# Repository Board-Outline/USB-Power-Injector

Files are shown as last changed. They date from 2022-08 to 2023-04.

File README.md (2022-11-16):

# USB Power Injector

The USB Power Injector allows a convenient way to power up USB 2.0 devices from a lab power supply, while still allowing data transfer from the device to the host. 

## The problem

When powering devices from a standard USB 2.0 port, either from a PC or from a standard USB hub, you never have the niceties that an adjustable lab style power supply has. 
During development that means you can’t set precise voltage and current limits. In the best case scenario, that means you can’t test under/over voltage protections. 
In the worst case, you run excessive current trough your device and you don’t even know that’s happened.
USB hubs tend to have overcurrent protection, but most don’t send the overcurrent event to the operating system. 
That can cause confusion and loss of time for a hardware engineer during development or to testing personnel during production.  

# Open Source Certified

The USB Power Injector is officially certified by the Open Source Hardware Association, with certificate number BG000082.

<p align="center">
  
</p>

The project was made using KiCad.

# License

<p align="center">
  
</p>

The project is released under the [Creative Commons Attribution-ShareAlike 4.0 International (CC BY-SA 4.0)](https://creativecommons.org/licenses/by-sa/4.0/).

Note: This is a human-readable summary of (and not a substitute for) the [license](https://creativecommons.org/licenses/by-sa/4.0/legalcode).

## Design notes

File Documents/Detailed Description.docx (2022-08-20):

Nikola Manolov

Board Outline

USB Power Injector

DETAILED DESCRIPTION


# Document Changes

Document Version | Date | Author | Changes
V1.0 | 2022.07.30 | Nikola Manolov | Document Creation

# Purpose and main design requirements

The USB Power Injector is an open source PCB designed by Board Outline.

Its intent is simple – Allow a convenient way to power up USB 2.0 devices from a lab power supply. When powering devices from a standard USB 2.0 port, either from a PC or from a standard USB hub, you never have the niceties that an adjustable lab style power supply has. During development that means you can’t set precise voltage and you can’t set current limits. In the best case scenario, that means you can’t test under/over voltage protections. In the worst case, you run excessive current trough your device and you don’t even know that’s happened. USB hubs tend to have overcurrent protection, but most don’t send the overcurrent event to the operating system. That can cause confusion and loss of time for a hardware engineer during development or to testing personnel during production.

When you get to that point its common to sacrifice a standard USB cable so you can connect an amp meter or to modify your board in a way that allows a bodged external supply to be used. Neither is pretty, quick or convenient.

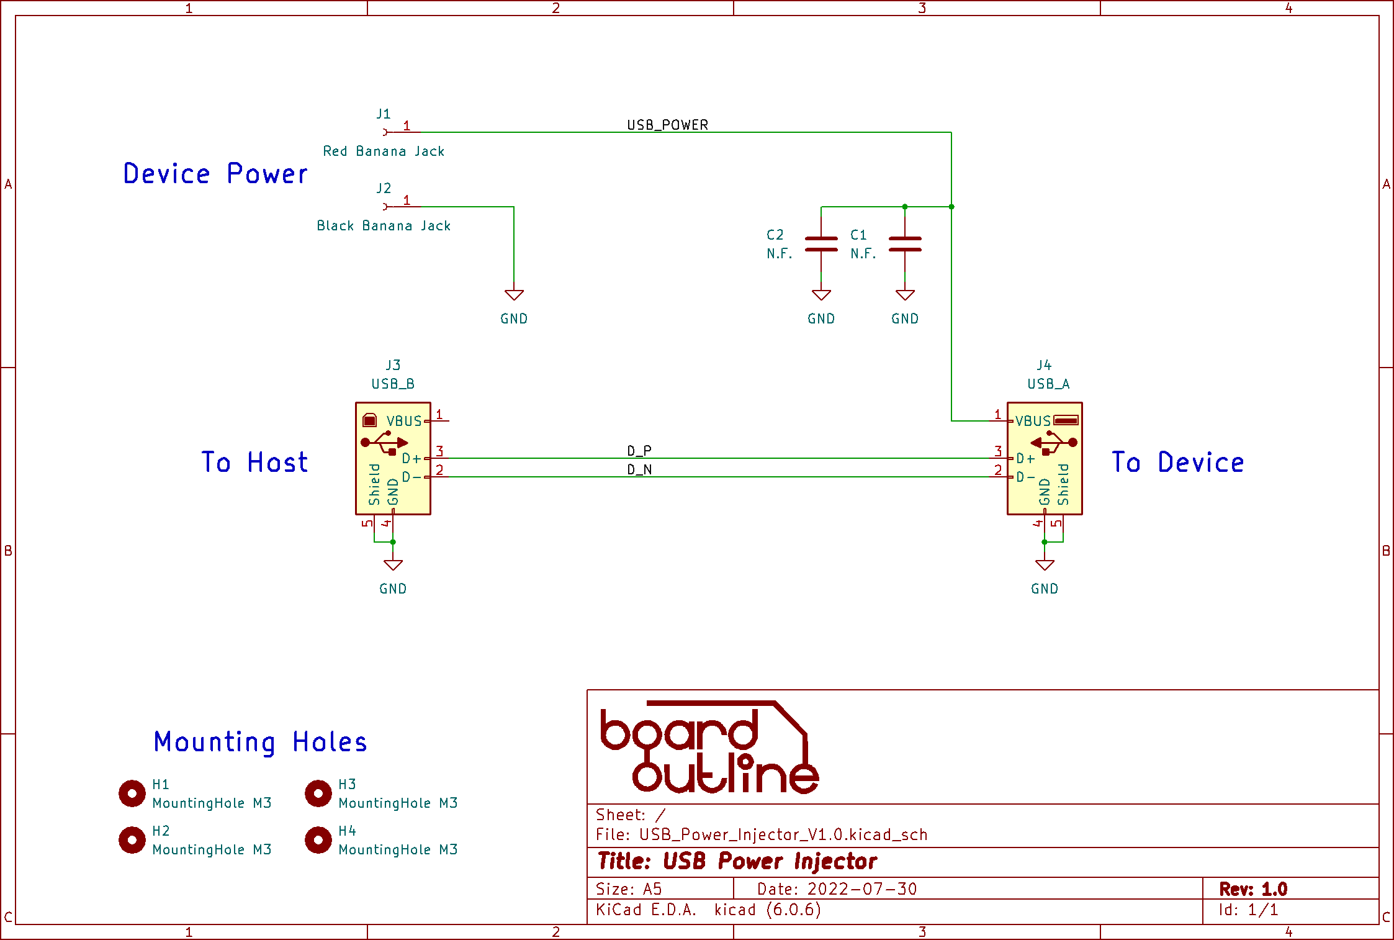
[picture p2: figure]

The USB Power Injector aims to remedy that by powering your device from two standard 4mm banana plugs, while still passing data between the host and device USB ports.
The device needs to be as transparent as possible for both the USB Data signals and for the power signals.

Figure 1. Schematic

# Detailed design explanation

The schematic is shown on Figure 1. The board was designed using KiCad 6. It’s a free and open source software, so anyone can read or edit the original design files.

## Design overview of the data path.

Connectors used for the data part are a horizontal USB B for the connection to the host and a horizontal USB A connector for the connection to the device under test. In order to get the required 90Ω impedance for USB lines, a 4 layer board was used. Stack used was JLC’s JLC7628. A conservative Space/Width of 5/8.1mils (0.127mm/0.2mm) was used, in order to get higher yield during manufacturing. As per the transparency requirement, no series or parallel components were used.

USB A and B connectors were used instead of two USB C connectors for the following reasons:

1. USB A and B connectors are physically stronger than USB C.
2. If two USB C connectors were used, the user could accidently connect his lab power supply to the power pins of the host USB port. That is potentially dangerous.

## Design overview of the power path.

Horizontal 4mm banana plugs were used in order to match the cable orientation of the USB ports/cables. Thus making the board less lightly to be moved by the cables by accident. The plugs are color coded – red for positive and black for negative. On the PCB they are positioned in the standard ¾ of an inch (19.04mm), so the user can use any standard banana plug accessories he may require.

As per the transparency requirement, no series elements, like diodes, were added. This allows the user to test any reverse polarity protection that may be present on the device under test. Parallel to the power line, unpopulated footprints for two 1210 capacitors were added close to the USB A connector. Their intent is to give the used the opportunity to add capacitors that would compensate the inductance of the power cables to the power supply. They are not populated in order to make sure the power injector does not improve the power delivery system of the device under test and making it seem like its working as intended, when in fact it is not.

Board OutlineUSB Power Injector[Publish Date]

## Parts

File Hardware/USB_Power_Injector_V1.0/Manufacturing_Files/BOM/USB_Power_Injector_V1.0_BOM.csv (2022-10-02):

Source: | D:\Board Outline\Repos\USB-Power-Injector\Hardware\USB_Power_Injector_V1.0\USB_Power_Injector_V1.0.kicad_sch
Date: | 02-Oct-22 17:32:15
Tool: | Eeschema (6.0.6)
Generator: | C:\Program Files\KiCad\6.0\bin\scripting\plugins/bom_csv_grouped_by_value.py
Component Count: | 4
Individual Components:
Item | Qty | Reference(s) | Value | LibPart | Footprint | Datasheet | Manufacturer | Manufacturer Part Number
 |  | J1 | Red Banana Jack | Connector:Conn_01x01_Female | USB_Power_Injector:4mm_Banana_Jack_Red_Deltron_571-0500 | ~ | Deltron | 571-0500
 |  | J2 | Black Banana Jack | Connector:Conn_01x01_Female | USB_Power_Injector:4mm_Banana_Jack_Black_Deltron_571-0100 | ~ | Deltron | 571-0100
 |  | J3 | USB_B | Connector:USB_B | USB_Power_Injector:USB_B_OST_USB-B1HSxx_Horizontal | ~ | CUI Devices | UJ2-BH-1-TH
 |  | J4 | USB_A | Connector:USB_A | USB_Power_Injector:USB_A_CONNFLY_DS1095-WNR0 | ~ | Stewart Connector / Bel | SS-52100-001
Collated Components:
Item | Qty | Reference(s) | Value | LibPart | Footprint | Datasheet | Manufacturer | Manufacturer Part Number
1 | 1 | J1 | Red Banana Jack | Connector:Conn_01x01_Female | USB_Power_Injector:4mm_Banana_Jack_Red_Deltron_571-0500 | ~ | Deltron | 571-0500
2 | 1 | J2 | Black Banana Jack | Connector:Conn_01x01_Female | USB_Power_Injector:4mm_Banana_Jack_Black_Deltron_571-0100 | ~ | Deltron | 571-0100
3 | 1 | J3 | USB_B | Connector:USB_B | USB_Power_Injector:USB_B_OST_USB-B1HSxx_Horizontal | ~ | CUI Devices | UJ2-BH-1-TH
4 | 1 | J4 | USB_A | Connector:USB_A | USB_Power_Injector:USB_A_CONNFLY_DS1095-WNR0 | ~ | Stewart Connector / Bel | SS-52100-001

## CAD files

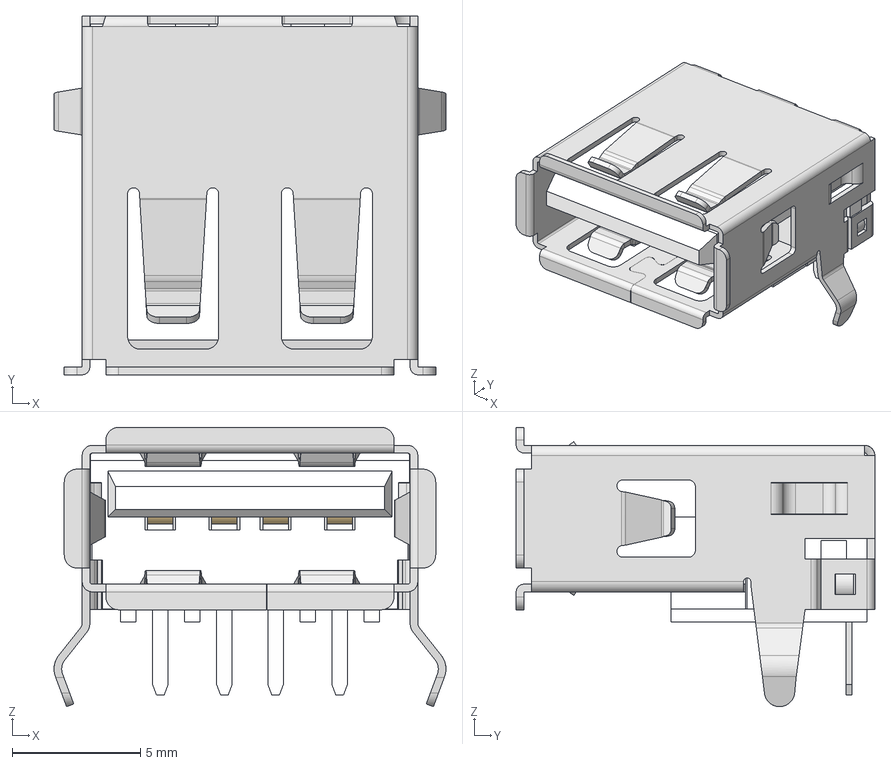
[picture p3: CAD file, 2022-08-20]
Hardware/USB_Power_Injector_V1.0/3D Models/Download_STP_61400416021 (rev1).stp
15.3 x 14.0 x 10.9 mm
61400416021_Insulator
61400416021_Contact Plating x 4
61400416021_Shielding

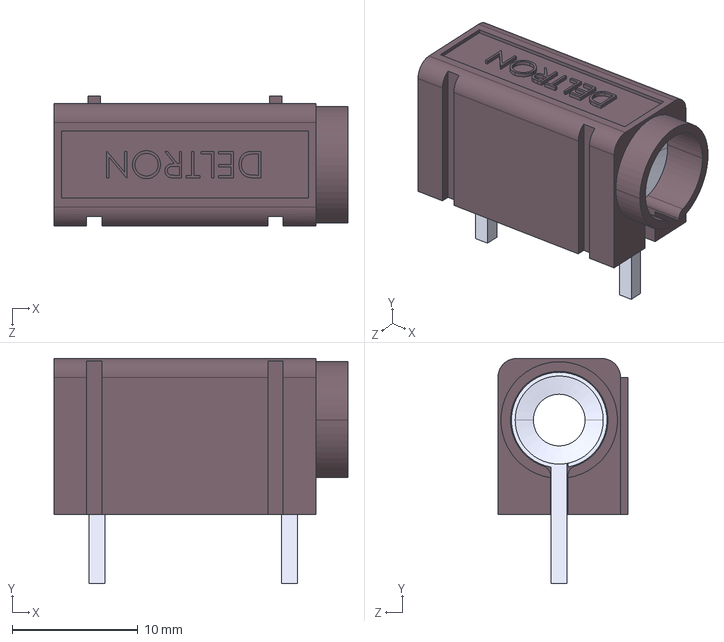
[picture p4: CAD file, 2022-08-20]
Hardware/USB_Power_Injector_V1.0/3D Models/deltron-571-0100-4mm-90deg-single-socket-data.step
23.4 x 17.9 x 10.3 mm

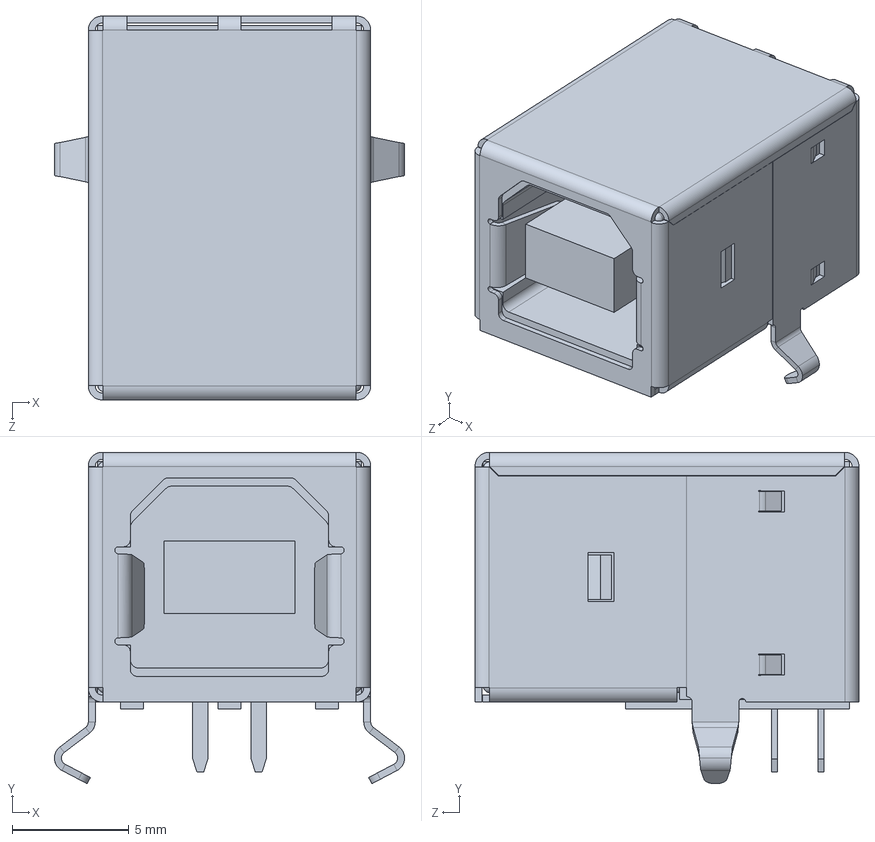
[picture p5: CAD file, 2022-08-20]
Hardware/USB_Power_Injector_V1.0/3D Models/CUI_DEVICES_UJ2-BH-1-TH.step
15.0 x 14.2 x 16.5 mm

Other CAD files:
Hardware/USB_Power_Injector_V1.0/3D Models/deltron-571-0500-4mm-90deg-single-socket-data.STEP

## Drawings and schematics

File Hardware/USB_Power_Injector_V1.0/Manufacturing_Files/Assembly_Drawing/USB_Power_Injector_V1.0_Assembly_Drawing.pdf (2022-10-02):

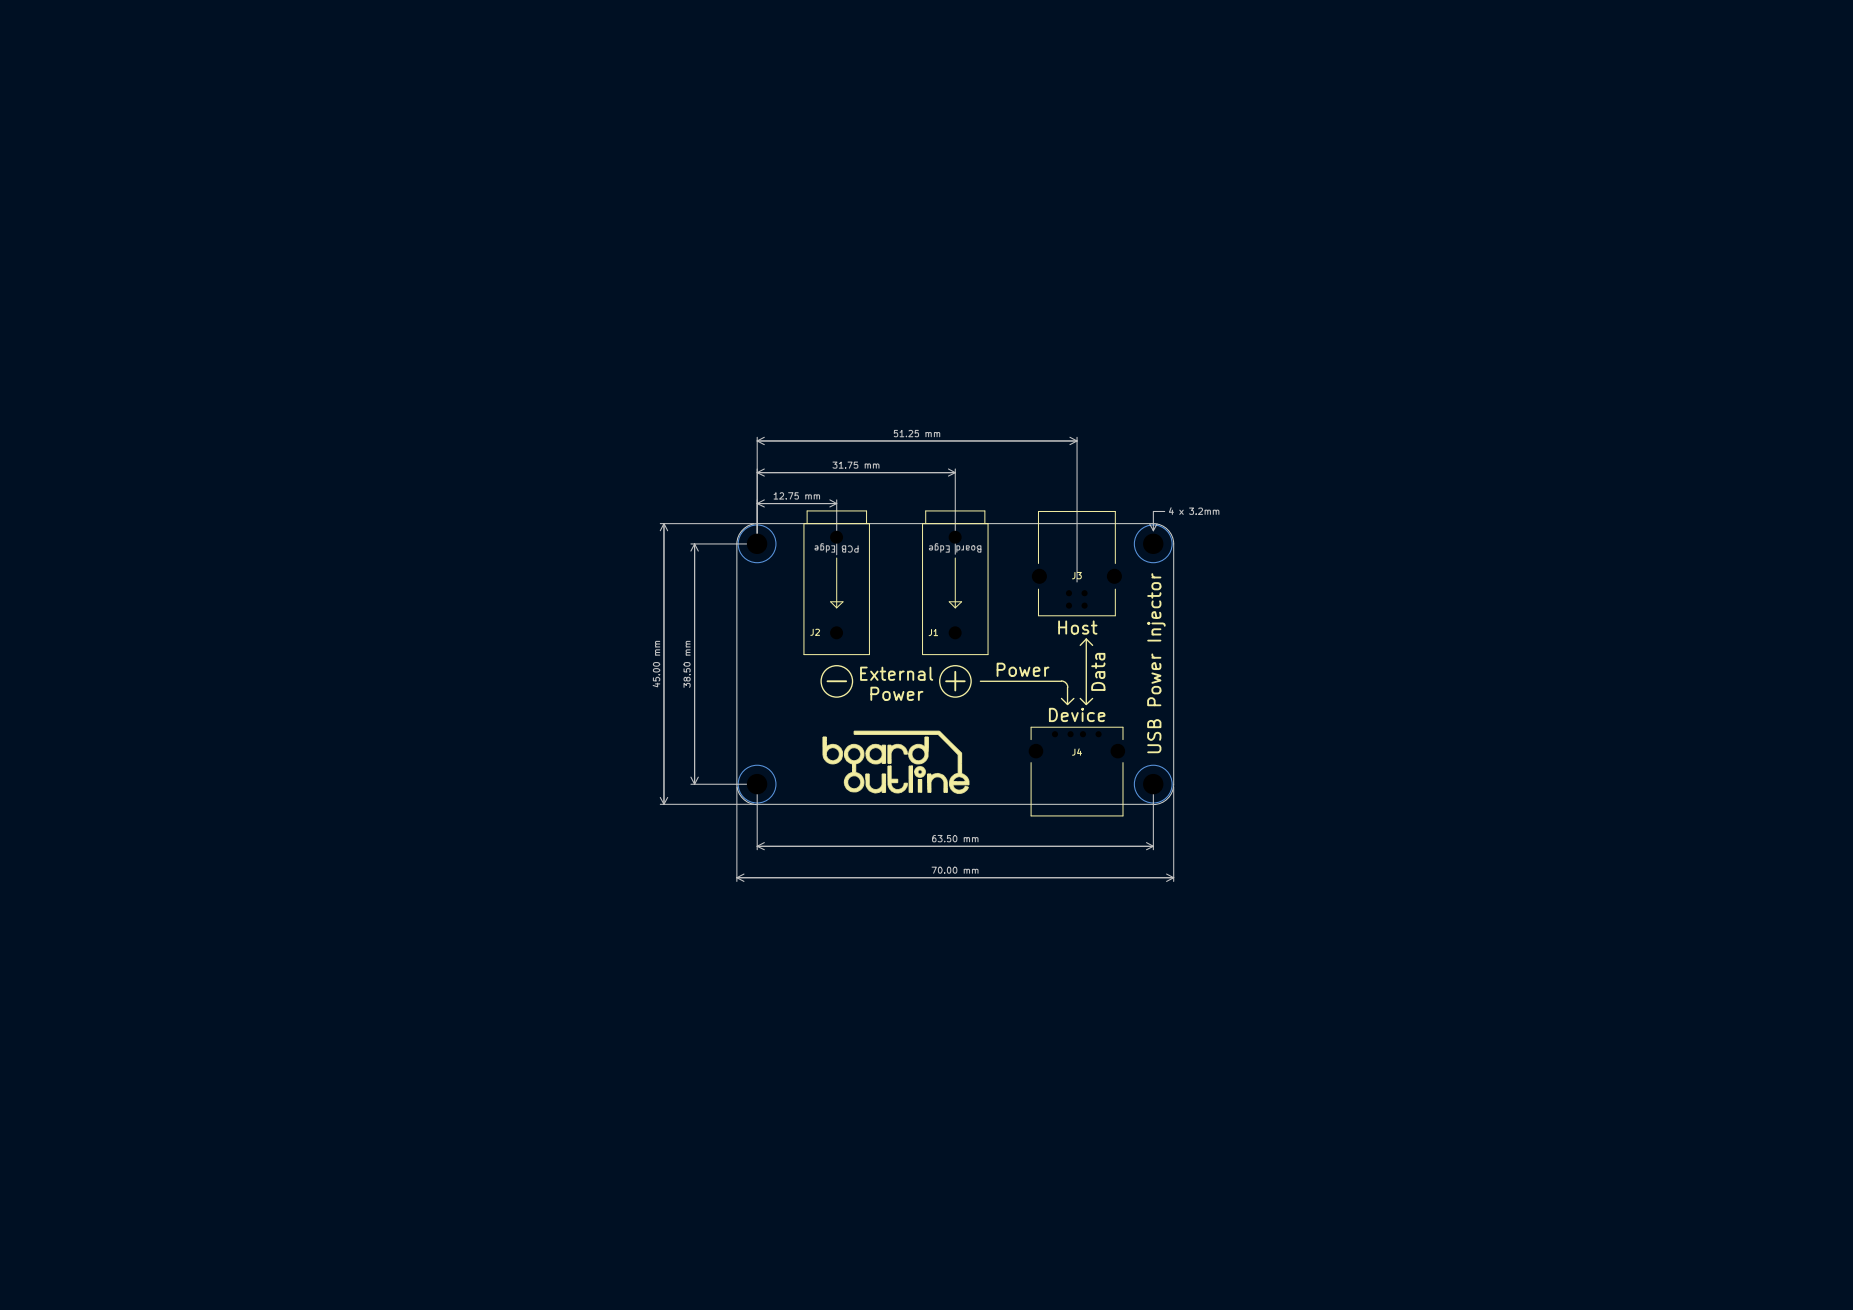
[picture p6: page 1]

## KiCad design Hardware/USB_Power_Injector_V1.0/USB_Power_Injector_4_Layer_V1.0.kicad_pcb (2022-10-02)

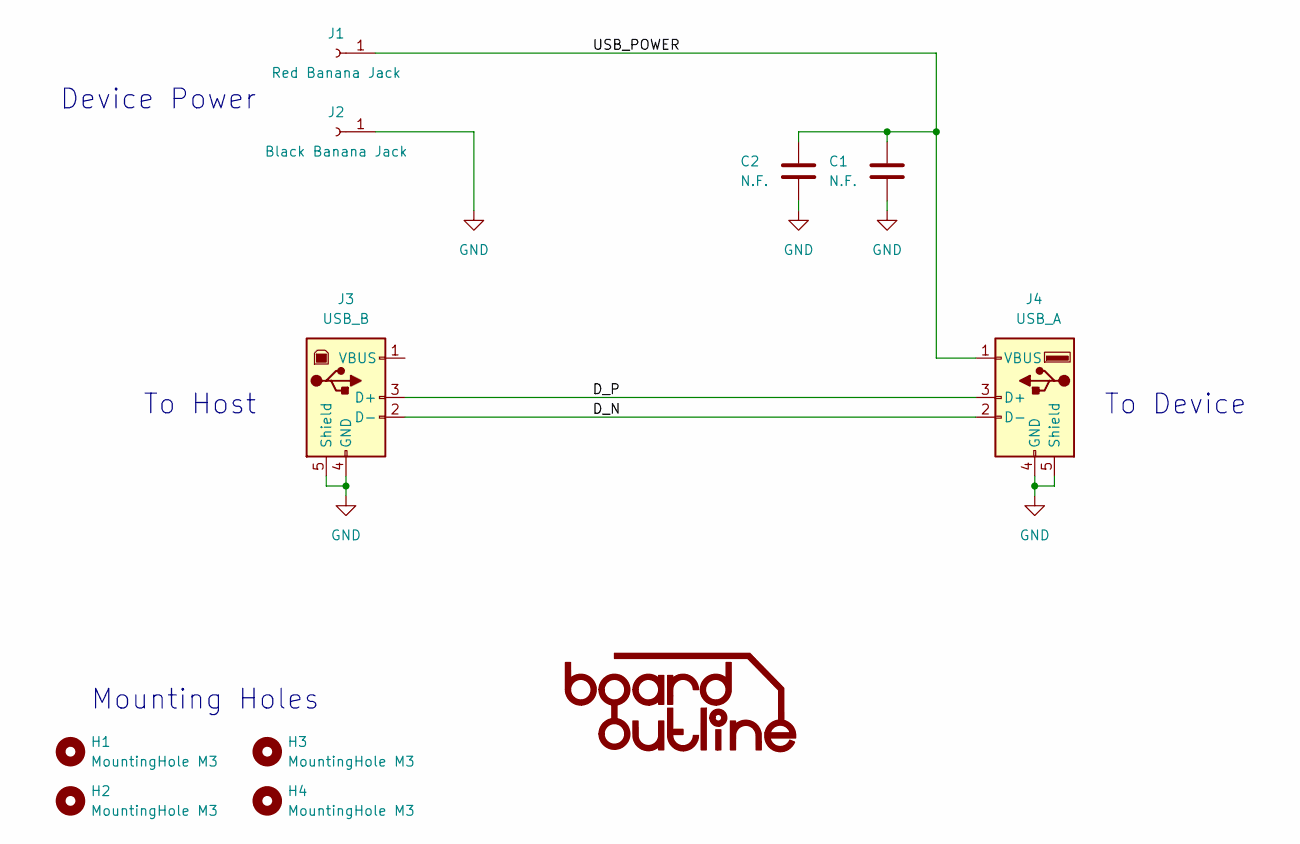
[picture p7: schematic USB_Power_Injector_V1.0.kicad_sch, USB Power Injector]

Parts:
C1, C2: N.F.; C_1210_3225Metric_Pad1.33x2.70mm_HandSolder
H1, H2, H3, H4: MountingHole M3; MountingHole_3.2mm_M3_ISO7380
J1: Red Banana Jack; 4mm_Banana_Jack_Red_Deltron_571-0500; Manufacturer Part Number 571-0500
J2: Black Banana Jack; 4mm_Banana_Jack_Black_Deltron_571-0100; Manufacturer Part Number 571-0100
J3: USB_B; USB_B_OST_USB-B1HSxx_Horizontal; Manufacturer Part Number UJ2-BH-1-TH
J4: USB_A; USB_A_CONNFLY_DS1095-WNR0; Manufacturer Part Number SS-52100-001

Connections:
/D_N: J3.2 (D-), J4.2 (D-)
/D_P: J3.3 (D+), J4.3 (D+)
/USB_POWER: C1.1, C2.1, J1.1, J4.1 (VBUS)
GND: C1.2, C2.2, J2.1, J3.4 (GND), J3.5 (Shield), J4.4 (GND), J4.5 (Shield)

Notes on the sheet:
Mounting Holes
To Device
Device Power
To Host

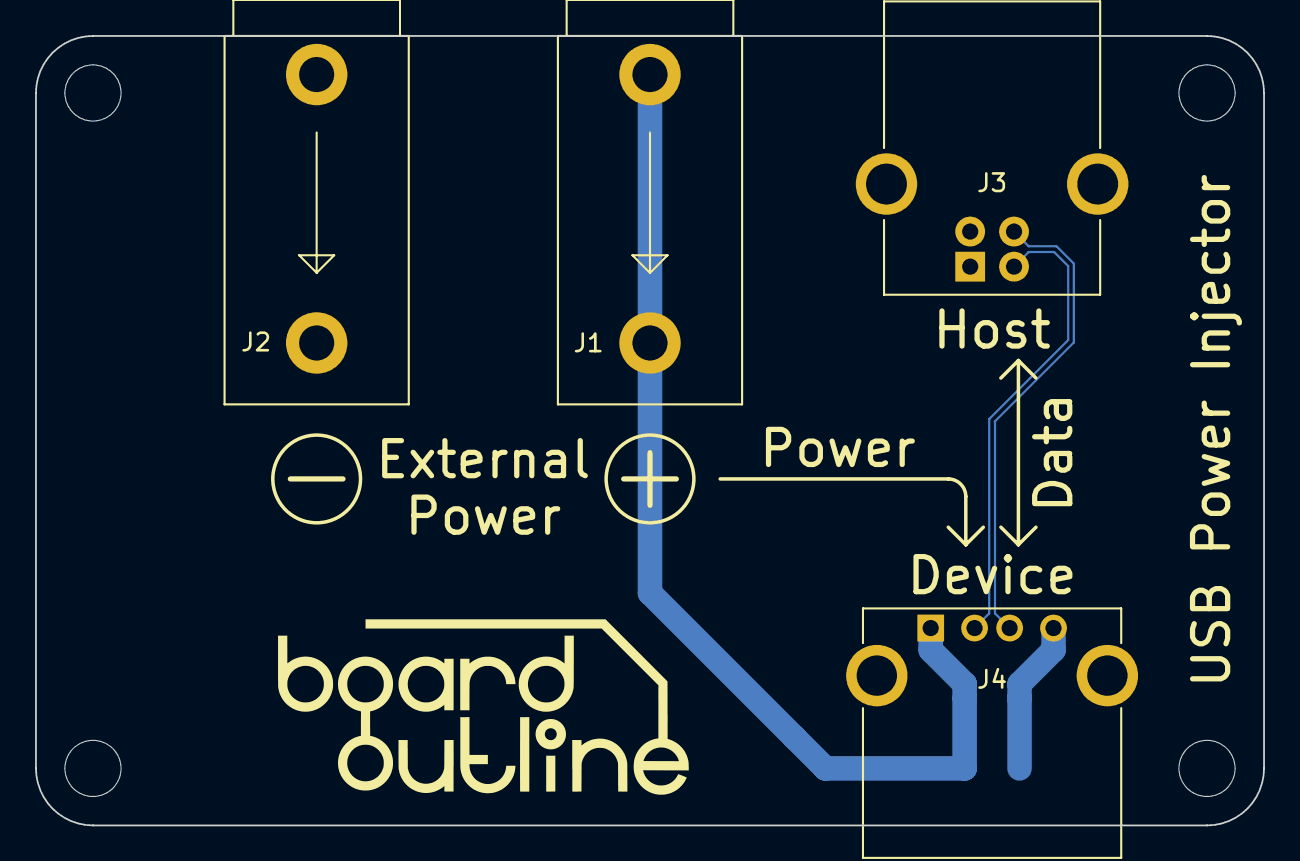
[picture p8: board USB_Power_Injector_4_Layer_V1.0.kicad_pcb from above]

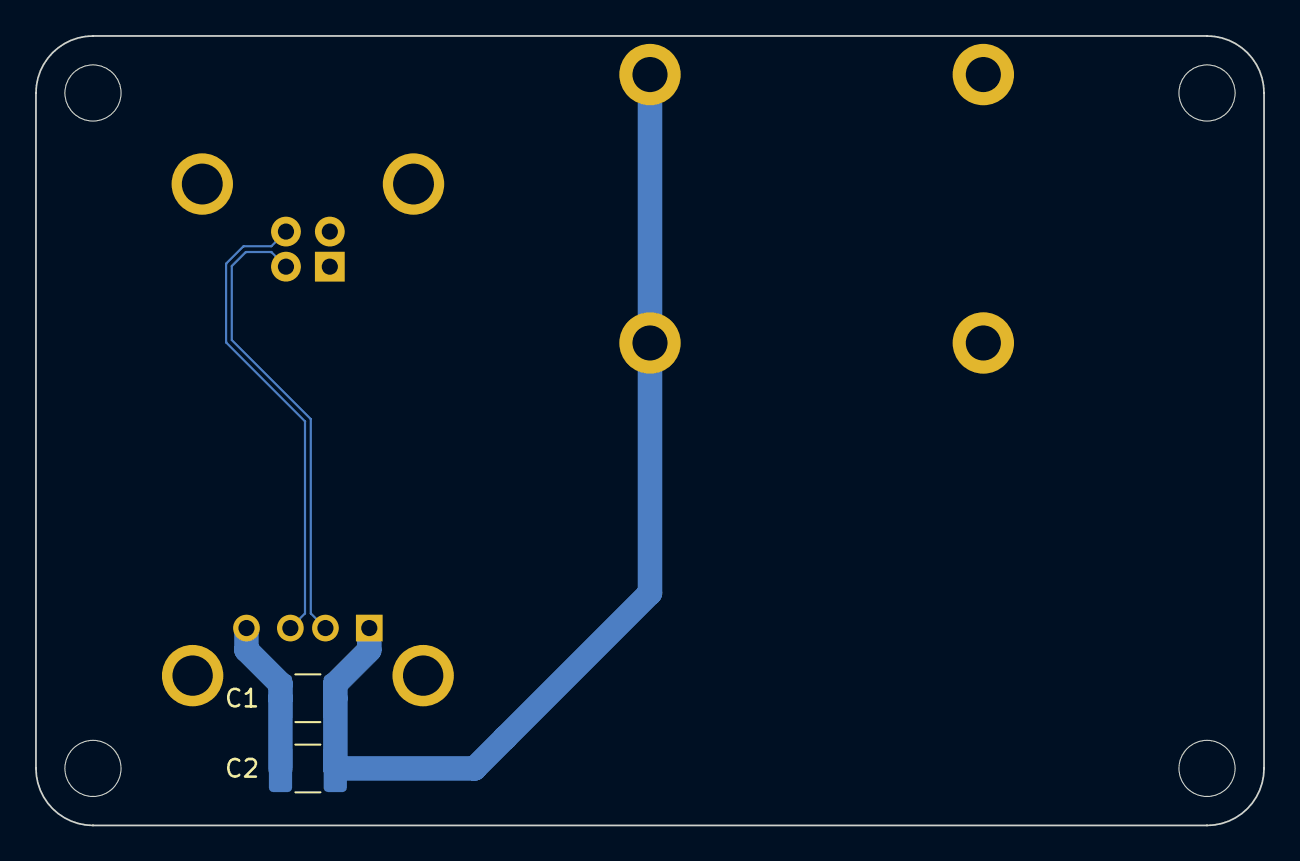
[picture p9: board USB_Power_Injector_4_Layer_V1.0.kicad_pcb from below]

Board: 4 copper layers, 70.0 x 45.0 mm, 10 parts (2 on the bottom side), 4 nets.

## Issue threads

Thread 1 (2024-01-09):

[Feature] USB 3.1 over USB-A version

tvercaut, 2024-01-09:
Thanks for sharing this. Would it be possible to extend the project to support USB 3.1 gen 2 (superspeed+) over USB-A?

Board-Outline, 2024-01-24:
Thank you for your comment and for you patience. I have tough about making a USB 3.x version of this project. Probably with a USB C connectors, since those are becoming the standard nowadays. Unfortunately I'm quite busy with my day job and other matters, so i don't have the time to work on this.

If i ever get the time to make it, it will be open source.
If you, or anyone else, would like to develop a USB 3.x version of the Power Injector, I would be extremely happy.

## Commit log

2022-09-24 BOM changes
    Excluded the mounting holes and N.F. components from BOM generation. BOM generated.
    [USB_Power_Injector_V1.0.csv, USB_Power_Injector_V1.0.kicad_sch]
2022-10-02 Added assembly drawing layers
    [USB_Power_Injector_V1.0.kicad_pcb, USB_Power_Injector_V1.0_BOM.csv]
2023-04-03 Added 2L version of the PCB
    [USB_Power_Injector_2_Layer_V1.0-B_Cu.gbl, USB_Power_Injector_2_Layer_V1.0-B_Mask.gbs, USB_Power_Injector_2_Layer_V1.0-B_Silkscreen.gbo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]
